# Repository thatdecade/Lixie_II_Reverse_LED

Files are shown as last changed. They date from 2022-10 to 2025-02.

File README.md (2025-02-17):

# Remix of Lixie II Open Hardware
Want to make your own Lixie II, but don't want to spend $$$$? You're in the right place. 

Based on the original work by Connor Nishijima: https://github.com/connornishijima/Lixie_II_OSHW

**Photo Album**
https://photos.app.goo.gl/PVswYqP2KvHP66T27

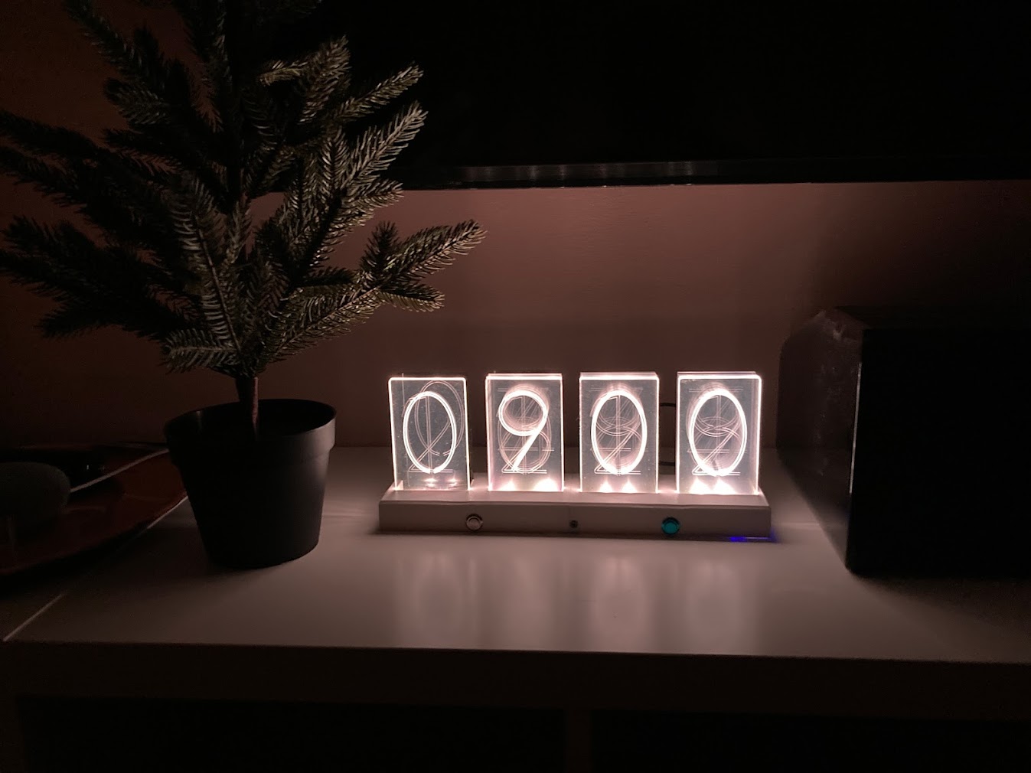
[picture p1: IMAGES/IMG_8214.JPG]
Assembled Lixie Clock with Reverse LEDs


## Remix Notes
- PCB redrawn with a new BOM, using reverse mount LEDs. https://www.adafruit.com/product/4960
  - Loosely based on Adafruit's RGB NeoKey https://www.adafruit.com/product/5157
  - One capacitor per LED
  - Transmission resistors for stable data
- EPS files for lasercutting were converted to DXF.
- Laser Cut files have been redrawn for smaller runs.  
  - Ordering one set = One Digit of the Display
  - Ponoko wil auto-panelize larger orders together.
  - Be sure to read https://help.ponoko.com/en/articles/4405518-getting-started-with-ponoko
- 3D Printed versions of some of the lasercut files

|Filename|Supplier|Material|Thickness|
| --- | --- | --- | --- |
|BASEx2.dxf|Ponoko|Black Melamine MDF|6.4|
|NUM0-9.dxf|Ponoko|Clear Acrylic|1.5|
|DECIMAL.dxf|Ponoko|Gray Translucent Acrylic|3|
|LIGHTFILTER.dxf|Ponoko|6061-T6 Aluminum|1|

- LixieII_Price_Calculator.xlsx calculates the cost (including electronics) based on how many you would like to make.  
Here are some BOM estimates as of Oct 28, 2022:

|QTY|Total Cost|Cost Each|
| --- | --- | --- |
|1|$166|$166|
|2|$233|$117|
|4|$255|$64|
|8|$392|$49|
|10|$446|$45|
|16|$665|$42|
|32|$1250|$39|
|200|$4740|$24|

## Todo

- Convert Lightplate into pcb gerbers for cheaper cutting

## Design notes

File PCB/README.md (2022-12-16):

Here you will find the files for the PCB.  

To order the PCBs pre-assembled, visit [pcbshopper](https://pcbshopper.com/) and click the Assembly tab.  Then you can fill out the form and compare pricing from different assemblers.

## Files for assembly:

* Lixie_II_Reverse_LED_GERBERS.zip
* Lixie_II_Reverse_LED_BOM.xlsx
* Lixie_II_Reverse_LED_PLACEMENT.xlsx

## Notes:

* If you don't have EagleCAD to open the .brd/.sch files, you can use the free version of Autodesk Fusion 360 and download Eagle Free.
* I use eagle to generate the .dxf files, ensuring alignment between the pcb and other layers.  

## Generating the DXF Files
Example for LIGHTFILTER.dxf
1. Open the the .brd file in eagle
1. View>Layer Settings: 
> * Select None
> * Select only the LIGHTFILTER/ENGRAVING layers
3. File>Export>DXF: 
> * Name the output file: LIGHTFILTER.dxf
> * Unselect Fill areas
> * Unselect Use wire widths
> * Set Units to mm
> * Press OK



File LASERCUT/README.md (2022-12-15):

These are the files to uplaod to Ponoko for laser cutting.  
Example below, how to fill out the order form and assign colors to each laser process.

Note: If you have a 3D printer, you can skip the BASE lasercut parts and use the 3d printed version instead.

ponoko_example_upload

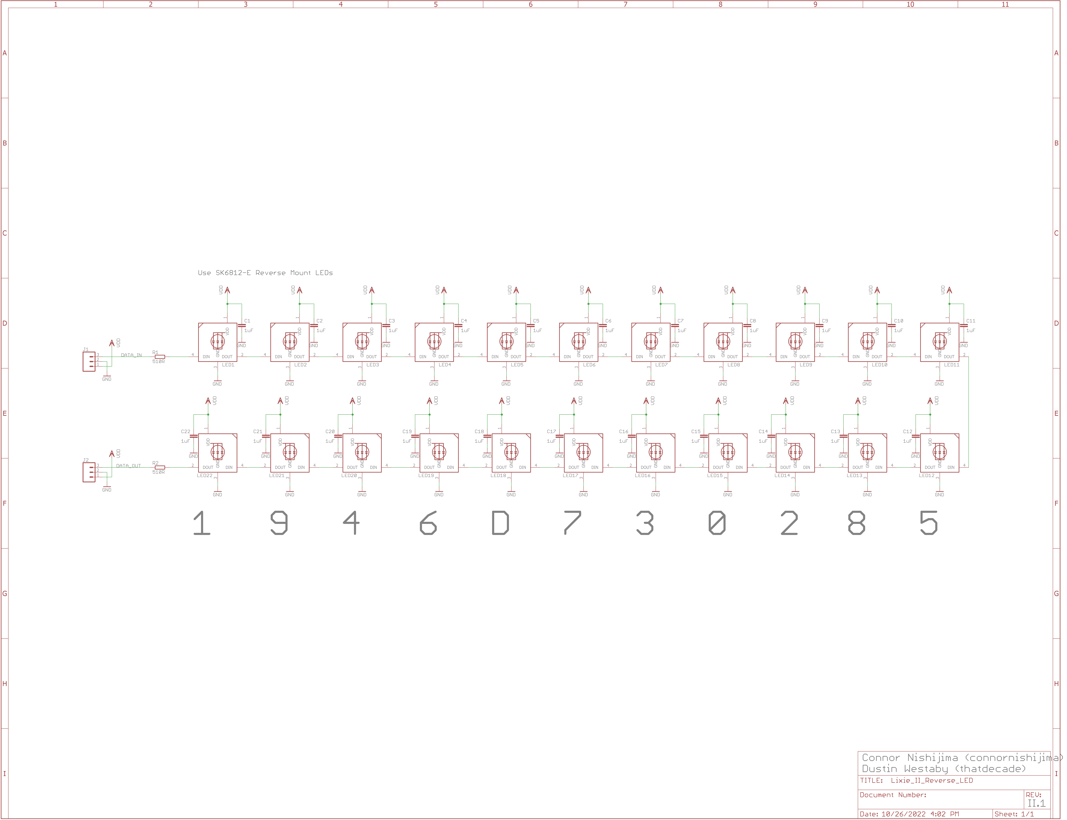
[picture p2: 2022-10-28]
PCB/Lixie_II_Reverse_LED_Schematic.png

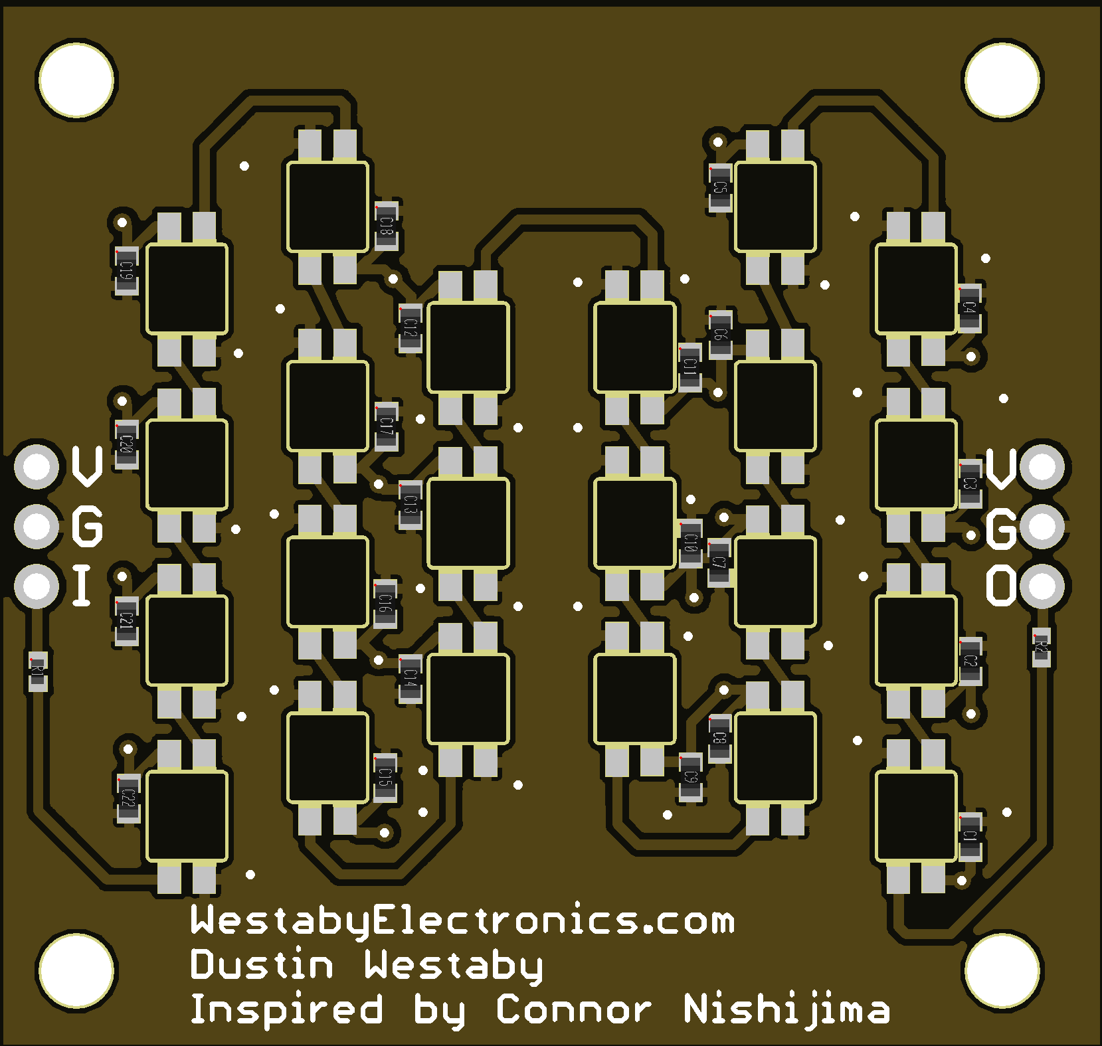
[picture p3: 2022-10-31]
PCB/Lixie_II_Reverse_LED_2D_Render.png

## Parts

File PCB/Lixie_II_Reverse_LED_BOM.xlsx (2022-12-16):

Comment | Designator | Footprint | JLCPCB Part # | Value
Capacitor | C1 | C0603 | C15849 | 1uF
Capacitor | C2 | C0603 | C15849 | 1uF
Capacitor | C3 | C0603 | C15849 | 1uF
Capacitor | C4 | C0603 | C15849 | 1uF
Capacitor | C5 | C0603 | C15849 | 1uF
Capacitor | C6 | C0603 | C15849 | 1uF
Capacitor | C7 | C0603 | C15849 | 1uF
Capacitor | C8 | C0603 | C15849 | 1uF
Capacitor | C9 | C0603 | C15849 | 1uF
Capacitor | C10 | C0603 | C15849 | 1uF
Capacitor | C11 | C0603 | C15849 | 1uF
Capacitor | C12 | C0603 | C15849 | 1uF
Capacitor | C13 | C0603 | C15849 | 1uF
Capacitor | C14 | C0603 | C15849 | 1uF
Capacitor | C15 | C0603 | C15849 | 1uF
Capacitor | C16 | C0603 | C15849 | 1uF
Capacitor | C17 | C0603 | C15849 | 1uF
Capacitor | C18 | C0603 | C15849 | 1uF
Capacitor | C19 | C0603 | C15849 | 1uF
Capacitor | C20 | C0603 | C15849 | 1uF
Capacitor | C21 | C0603 | C15849 | 1uF
Capacitor | C22 | C0603 | C15849 | 1uF
Resistor | R1 | R0402 | C25123 | 510R
Resistor | R2 | R0402 | C25123 | 510R
Connector | J1 | 1X03_NO_SILK |  | 1x3
Connector | J2 | 1X03_NO_SILK |  | 1x3
Reverse Mount LED | LED1 | SK6812-E-SMD |  | SK6812MINI_REV
Reverse Mount LED | LED2 | SK6812-E-SMD |  | SK6812MINI_REV
Reverse Mount LED | LED3 | SK6812-E-SMD |  | SK6812MINI_REV
Reverse Mount LED | LED4 | SK6812-E-SMD |  | SK6812MINI_REV
Reverse Mount LED | LED5 | SK6812-E-SMD |  | SK6812MINI_REV
Reverse Mount LED | LED6 | SK6812-E-SMD |  | SK6812MINI_REV
Reverse Mount LED | LED7 | SK6812-E-SMD |  | SK6812MINI_REV
Reverse Mount LED | LED8 | SK6812-E-SMD |  | SK6812MINI_REV
Reverse Mount LED | LED9 | SK6812-E-SMD |  | SK6812MINI_REV
Reverse Mount LED | LED10 | SK6812-E-SMD |  | SK6812MINI_REV
Reverse Mount LED | LED11 | SK6812-E-SMD |  | SK6812MINI_REV
Reverse Mount LED | LED12 | SK6812-E-SMD |  | SK6812MINI_REV
Reverse Mount LED | LED13 | SK6812-E-SMD |  | SK6812MINI_REV
Reverse Mount LED | LED14 | SK6812-E-SMD |  | SK6812MINI_REV
Reverse Mount LED | LED15 | SK6812-E-SMD |  | SK6812MINI_REV
Reverse Mount LED | LED16 | SK6812-E-SMD |  | SK6812MINI_REV
Reverse Mount LED | LED17 | SK6812-E-SMD |  | SK6812MINI_REV
Reverse Mount LED | LED18 | SK6812-E-SMD |  | SK6812MINI_REV
Reverse Mount LED | LED19 | SK6812-E-SMD |  | SK6812MINI_REV
Reverse Mount LED | LED20 | SK6812-E-SMD |  | SK6812MINI_REV
Reverse Mount LED | LED21 | SK6812-E-SMD |  | SK6812MINI_REV
Reverse Mount LED | LED22 | SK6812-E-SMD |  | SK6812MINI_REV

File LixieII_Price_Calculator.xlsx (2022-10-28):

 |  |  |  |  | Qty
 |  |  |  | ENTER QUANTITY YOU WOULD LIKE TO MAKE HERE ----> | 10
 |  |  |  | Estimated Cost-----> | $445.85
 |  |  |  |  |  |  |  |  |  |  |  |  | Prices quoted on 10/27/2022 from ponoko.com
Description | Supplier | Material | Thickness |  | Qty | Price | Handling | Shipping | Each | Qty per Display Digit | Cost Per Display Digit | Notes | Price Lookups | BASES | NUMS0-9 | DECIMAL | Light Filter | Price Lookups | PCB | Price Lookups | LEDs | Price Lookups | Gloves | Price Lookups | Screw 35mm | Screw 25mm | Price Lookups | Nylon Washer | Price Lookups | Nut | Price Lookups | Female Wire
BASEx2.dxf | Ponoko | Black Melamine MDF | 6.4 |  | 10 | $77.40 |  |  | $7.74 | 1 | $7.74 |  | 1 | 16.62 | 31.01 | 10.76 | 8.84 | 5 | 11.5 | 50 | 6.46 | 100 | 12.75 | 200 | 8.16 | 6.56 | 100 | 2.17 | 50 | 3.81 | 40 | 2.24
NUM0-9.dxf | Ponoko | Clear Acrylic | 1.5 |  | 10 | $171.70 |  |  | $17.17 | 1 | $17.17 |  | 4 | 9.1 | 19.22 | 5.62 | 4.25 | 10 | 14.5 | 100 | 10.2 | 200 | 25.5 | 400 | 16.32 | 13.12 | 200 | 3.4 | 100 | 8.02 | 80 | 3.11
DECIMAL.dxf | Ponoko | Gray Translucent Acrylic | 3.0 |  | 10 | $34.90 |  |  | $3.49 | 1 | $3.49 |  | 5 | 8.89 | 18.11 | 5.33 | 3.96 | 15 | 16 | 200 | 16.57 | 300 | 38.25 | 600 | 24.48 | 19.68 | 300 | 4.63 | 150 | 10.99 | 120 | 3.98
LIGHTFILTER.dxf | Ponoko | 6061-T6 Aluminum | 1.0 |  | 10 | $33.40 |  |  | $3.34 | 1 | $3.34 | Replace with PCB? | 8 | 8.02 | 17.54 | 4.84 | 3.48 | 20 | 16.8 | 300 | 24.05 | 400 | 51 | 800 | 32.64 | 26.24 | 400 | 7.28 | 200 | 13.97 | 160 | 4.85
 |  |  |  |  |  |  |  |  |  |  |  |  | 10 | 7.74 | 17.17 | 3.49 | 3.34 | 25 | 17.6 | 500 | 36.12 | 500 | 63.75 | 1000 | 40.8 | 32.8 | 500 | 8.59 | 250 | 16.95 | 200 | 6.86
Description | Supplier | Link |  |  | Qty | Price |  | Shipping | Each | Qty per Display Digit | Cost Per Display Digit | Notes | 50 | 4.91 | 12.02 | 2.7 | 1.91 | 30 | 18.4 | 1000 | 65.87 | 600 | 76.5 | 1200 | 48.96 | 39.36 | 600 | 9.89 | 300 | 19.92 | 240 | 7.73
PCB | JLC | PCB |  |  | 10 | $24.50 |  | $40.00 | $6.45 | 1 | $6.45 |  | 100 | 4.43 | 10.59 | 2.03 | 1.37 | 50 | 22.9 | 2000 | 121.97 | 700 | 89.25 | 1400 | 57.12 | 45.92 | 700 | 11.19 | 350 | 22.9 | 280 | 8.6
Reverse Mount LEDs | veromount Official Store | https://www.aliexpress.us/item/3256804063632410.html?mp=1&_randl_shipto=US |  |  | 300 | $24.05 |  |  | $0.08 | 22 | $1.76 |  | 500 | 3.21 | 8.36 | 1.57 | 1.12 | 75 | 59.16 | 4000 | 243.94 |  |  |  |  |  | 1000 | 15.11 | 500 | 31.83 | 320 | 9.47
Nitrile Gloves | Sinier Store Store | https://www.aliexpress.us/item/3256803590949003.html?curPageLogUid=DwKQPqTq5PrM |  |  | 100 | $12.75 |  |  | $0.13 | 2 | $0.26 |  | 1000 | 2.84 | 7.22 | 1.4 | 0.99 | 100 | 64.76 | 6000 | 365.91 |  |  |  |  |  | 1500 | 21.63 | 1000 | 61.59 | 360 | 10.34
35mm M3 Screw | SHOUZHENG FASTENER Store | https://www.aliexpress.com/item/3256804033774565.html?spm=a2g0o.cart.0.0.26bd38daxLe5zc&mp=1 |  |  | 200 | $8.16 |  |  | $0.04 | 4 | $0.16 |  | 5000 | 1.89 | 4.42 | 1.05 | 0.71 | 125 | 70.36 | 8000 | 487.88 |  |  |  |  |  | 2000 | 28.15 | 1500 | 91.35 | 400 | 11.21
25mm M3 screw | SHOUZHENG FASTENER Store | https://www.aliexpress.com/item/3256804033774565.html?spm=a2g0o.cart.0.0.26bd38daxLe5zc&mp=1 |  |  | 200 | $6.56 |  |  | $0.03 | 4 | $0.13 |  | 10000 | 1.5 | 3.73 | 0.87 | 0.6 | 150 | 76.06 |  |  |  |  |  |  |  | 2500 | 34.67 | 3000 | 180.63 | 440 | 12.08
Nylon washer | SHOUZHENG FASTENER Store | https://www.aliexpress.com/item/3256803969060157.html?spm=a2g0o.cart.0.0.1a8138davO6E52&mp=1 |  |  | 100 | $2.17 |  |  | $0.02 | 8 | $0.17 |  |  |  |  |  |  | 200 | 87.26 |  |  |  |  |  |  |  |  |  |  |  | 480 | 12.95
M3 Flange Nut | SHOUZHENG FASTENER Store | https://www.aliexpress.com/item/3256804055381890.html?spm=a2g0o.cart.0.0.4f8138daJxUMmj&mp=1 |  |  | 100 | $8.02 |  |  | $0.08 | 8 | $0.64 |  |  |  |  |  |  | 250 | 98.56 |  |  |  |  |  |  |  |  |  |  |  | 520 | 13.82
Female Jumper Wires 10cm | Fnd Chips Store | https://www.aliexpress.us/item/3256804425682359.html?curPageLogUid=pjq9i1GZgUdJ |  |  | 40 | $2.24 |  |  | $0.06 | 3 | $0.17 |  |  |  |  |  |  |  |  |  |  |  |  |  |  |  |  |  |  |  | 560 | 14.69
ESP8266 |  |  |  |  |  |  |  |  |  |  |  |  |  |  |  |  |  |  |  |  |  |  |  |  |  |  |  |  |  |  | 600 | 15.56
 |  |  |  |  |  |  |  |  |  |  |  |  |  |  |  |  |  |  |  |  |  |  |  |  |  |  |  |  |  |  | 640 | 16.43
 | Estimations (Pre-Calculated)
 | QTY | Total Cost | Cost Each
 | 1 | $165.88 | $165.88
 | 2 | $233.11 | $116.555
 | 4 | $255.15 | $63.7875
 | 8 | $392.01 | $49.00125
 | 10 | $445.85 | $44.585
 | 16 | $665.73 | $41.608125
 | 32 | $1250.45 | $39.0765625
 | 200 | $4739.73 | $23.69865

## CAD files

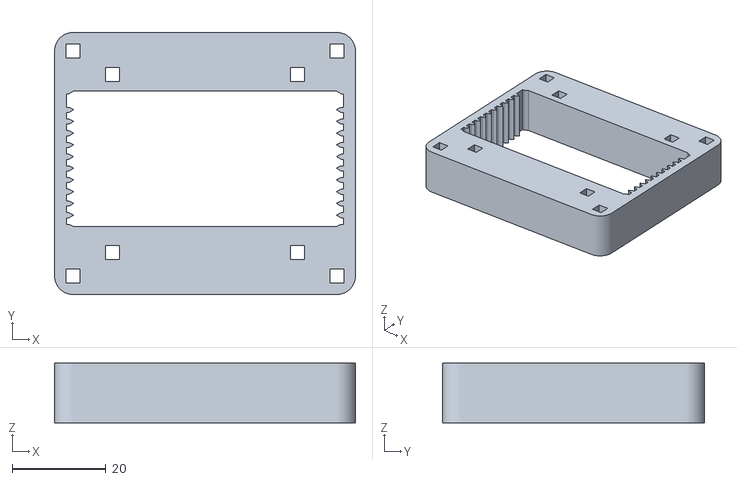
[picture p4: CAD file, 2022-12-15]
3D Printing/BASE.stl
64.3 x 56.0 x 12.8

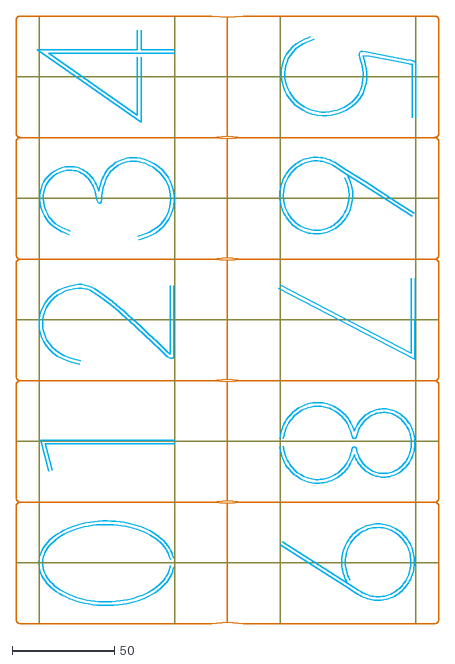
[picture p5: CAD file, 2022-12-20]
LASERCUT/NUM0-9.dxf
206.2 x 296.7

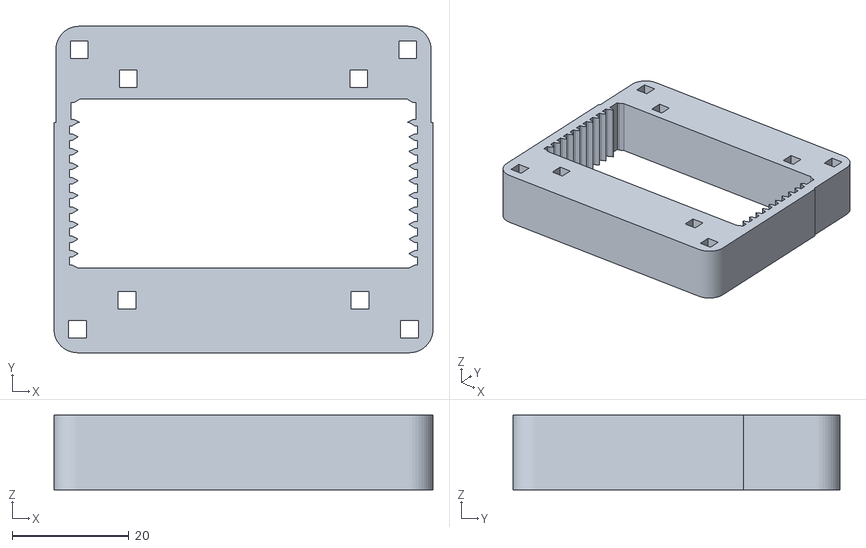
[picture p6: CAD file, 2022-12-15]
3D Printing/BASE-Loose_Fit.stl
64.9 x 56.0 x 12.8

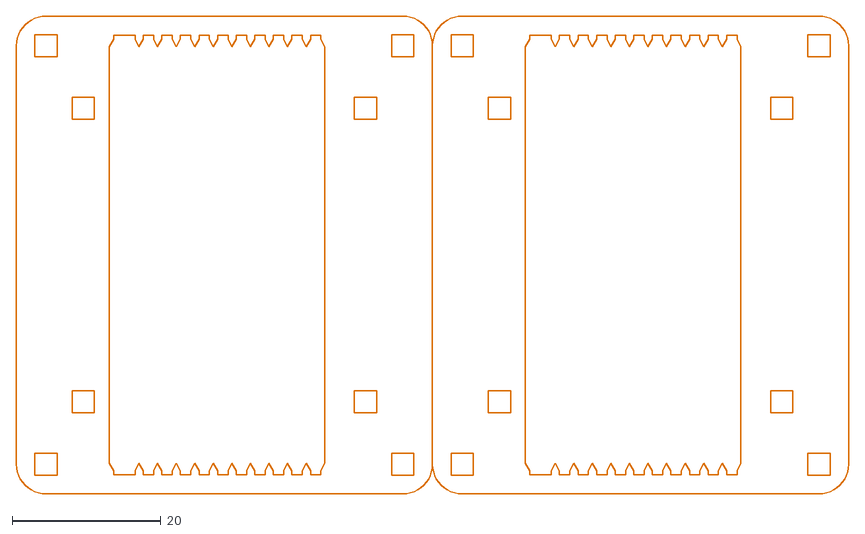
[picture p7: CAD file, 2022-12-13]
LASERCUT/BASEx2.dxf
112.0 x 64.3

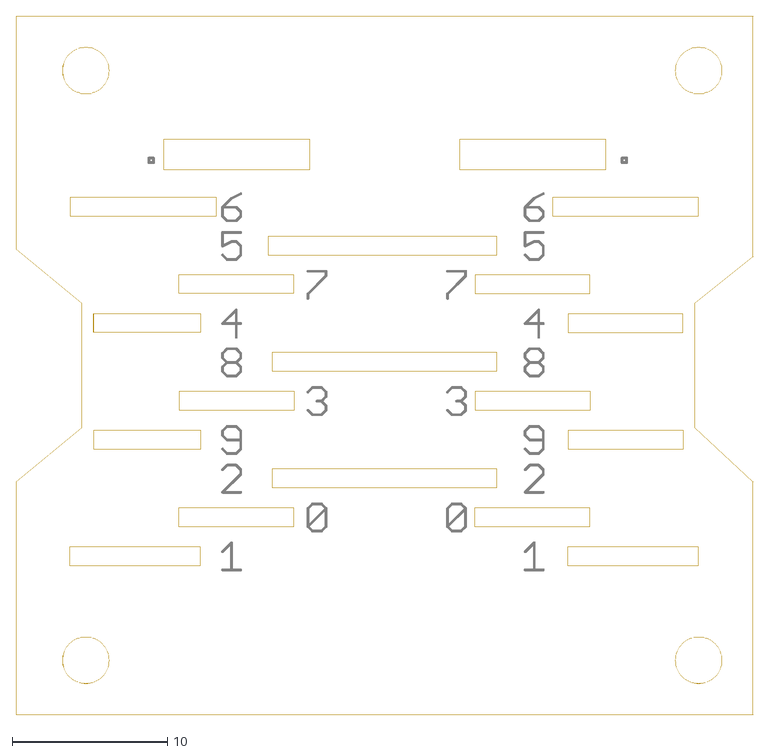
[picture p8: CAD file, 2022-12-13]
LASERCUT/LIGHTFILTER.dxf
47.5 x 45.0

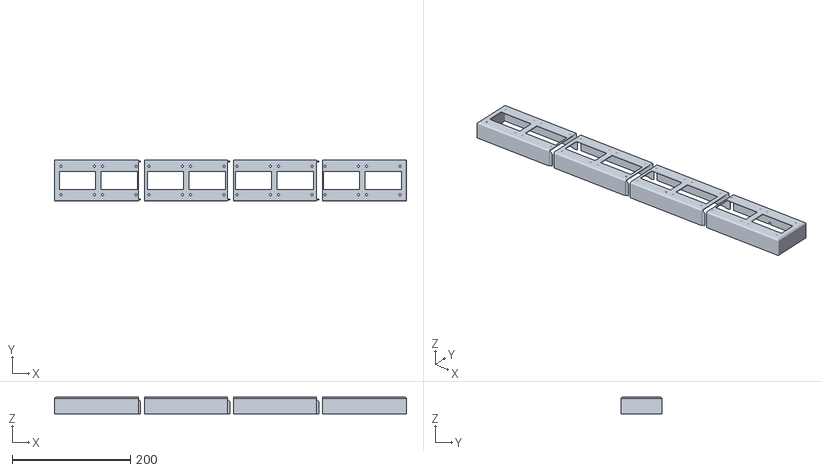
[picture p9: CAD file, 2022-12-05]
3D Printing/Lixie_II_Case_8_digits.stl
594.4 x 70.0 x 28.0

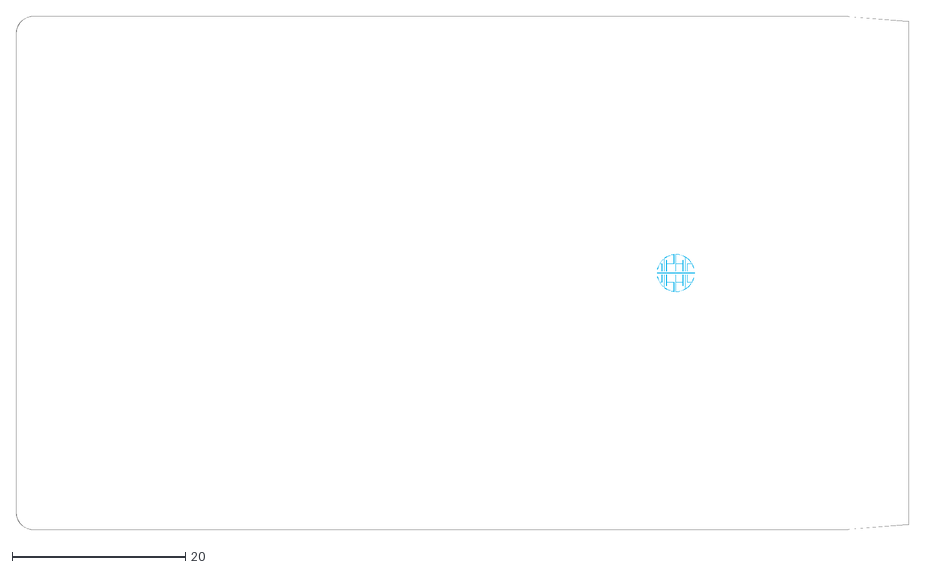
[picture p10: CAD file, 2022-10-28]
LASERCUT/DECIMAL.dxf
103.1 x 59.3

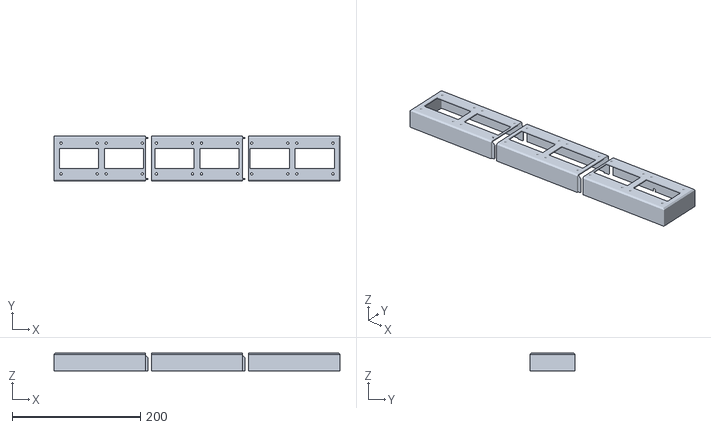
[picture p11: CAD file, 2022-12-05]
3D Printing/Lixie_II_Case_6_digits.stl
445.8 x 70.0 x 28.0

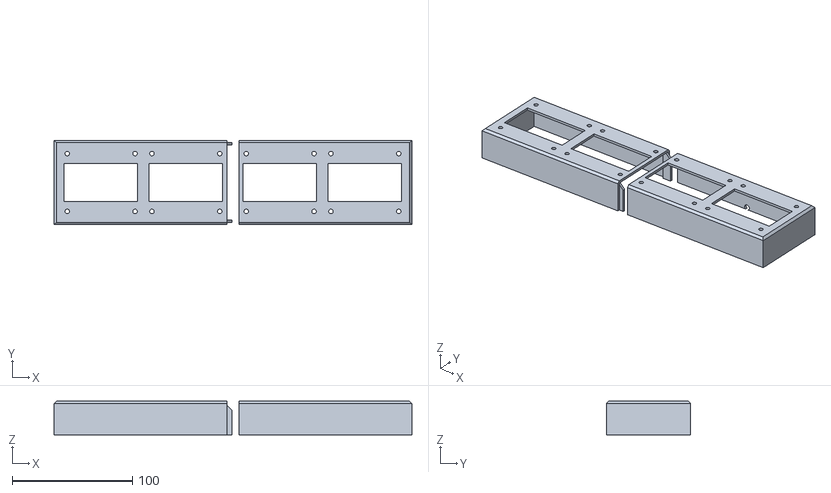
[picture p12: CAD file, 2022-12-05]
3D Printing/Lixie_II_Case_4_digits.stl
297.2 x 70.0 x 28.0

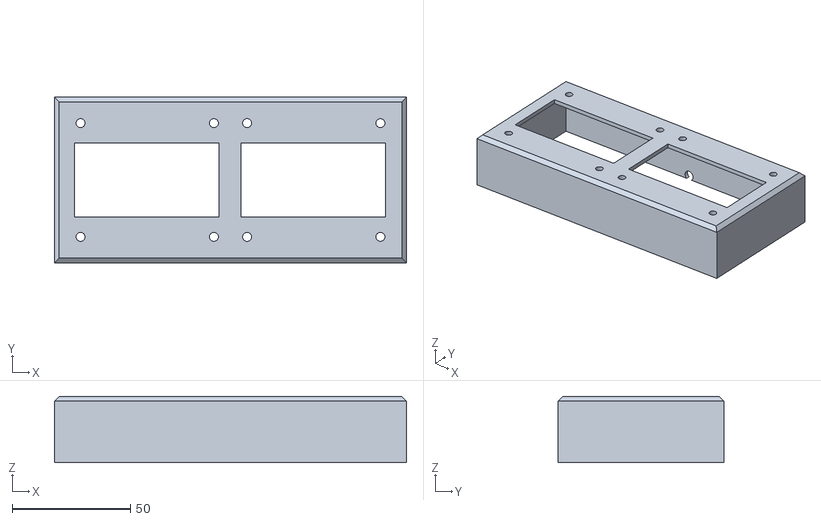
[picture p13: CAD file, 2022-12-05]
3D Printing/Lixie_II_Case_2_digits.stl
148.6 x 70.0 x 28.0

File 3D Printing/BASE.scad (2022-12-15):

/* This is a customizable housing for lixie displays

    Dustin Westaby 
    Nov 2022

    USAGE:
    
    Enter the number of displays you want, and you will get an object that you can print as is, or split up for your printer
    
*/

// ********************
// USER DEFINES
// ********************
// Set options here

black_melamine_mdf_thickness = 6.4;
mdf_stack_height = 2;

want_tolerance_for_acrylic  = 1;
want_screw_threaded_inserts = 1;

// ********************
// CALCULATED
// ********************

loose_fit = 2.0;
slide_fit = 0.2;
friction_fit = 0.02;

total_height = black_melamine_mdf_thickness*mdf_stack_height;

// ********************
// MODULES
// ********************

difference()
{
    union()
    {
        base_slice("3mm holder");
        base_slice("1.5mm holder");
    }
    if(want_screw_threaded_inserts) threaded_inserts();
}

module base_slice(part="3mm holder")
{
    scale_adj      = (part=="3mm holder") ? 1 : 1.01;
    x_position_adj = (part=="3mm holder") ? 0 : -0.25;
    
    translate([x_position_adj,0,0])
    linear_extrude(height=total_height)
    {
        scale([scale_adj,1,1]) //no scale change
        difference()
        {
            if(want_screw_threaded_inserts) import("BASE_NoHoles.dxf");
            else                            import("BASE.dxf");
            
            if(want_tolerance_for_acrylic)
            {
                if(part=="3mm holder") translate([-8,-8,0]) square(size = [65, 42]);
                else translate([-8,42-8,0]) square(size = [65, 20]);
            }

        }
    }
}

module threaded_inserts()
{
    
    insert_hole_diameter = 3.73 + slide_fit;
    $fn=25;
    
    //inner holes
    translate([ 4.7,41.54,-1]) cylinder(d=insert_hole_diameter, h= total_height+2);
    translate([44.2,41.54,-1]) cylinder(d=insert_hole_diameter, h= total_height+2);
    translate([ 4.7,3.54,-1]) cylinder(d=insert_hole_diameter, h= total_height+2);
    translate([44.2,3.54,-1]) cylinder(d=insert_hole_diameter, h= total_height+2);
    
    //outer holes
    translate([ -3.7,46.55,-1]) cylinder(d=insert_hole_diameter, h= total_height+2);
    translate([52.6,46.55,-1]) cylinder(d=insert_hole_diameter, h= total_height+2);
    translate([ -3.7,-1.45,-1]) cylinder(d=insert_hole_diameter, h= total_height+2);
    translate([52.6,-1.45,-1]) cylinder(d=insert_hole_diameter, h= total_height+2);
}

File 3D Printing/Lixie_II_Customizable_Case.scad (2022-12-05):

/* This is a customizable housing for lixie displays

    Dustin Westaby 
    Nov 2022

    USAGE:
    
    Enter the number of displays you want, and you will get an object that you can print as is, or split up for your printer
    
*/

// ********************
// USER DEFINES
// ********************
// Set options here

digits = 2; //Min is 1

chamfer = 2;

screw_hole_diameter = 3; //M3 = 3mm

want_button = 0;

want_power_cable = 1;

want_pre_cuts_and_glue_tabs = 1;

switch_hole_diameter = 12; //set want_button=1

usb_cable_diameter = 5;  //set want_power_cable=1

window_x = 59.05;
window_y = 29.20;

max_printer_bed_size = 180; //set want_pre_cuts_and_glue_tabs=1, Prusa Mk3 = 21cm (8.3")

// ********************
// CALCULATED
// ********************

side_wall_thickness = 2; //2 or 3mm

top_wall_thickness = 2 ;

loose_fit = 2.0;
slide_fit = 0.2;
friction_fit = 0.02;

center_digits = digits-2;

edge_length = 74.3;
center_length = 70.3;

outer_length_x = edge_length*2 + center_digits*center_length;
outer_width_y  = 70;

outer_depth_z  = 26 + top_wall_thickness;

switch_hole_z_offset_from_center = outer_depth_z/2-top_wall_thickness/2;

window_x_size_adj = window_x + loose_fit;
window_y_size_adj = window_y + loose_fit;

glue_tab_insert_depth = 4;

// ********************
// MODULES
// ********************

//max_printer_bed_size
if((want_pre_cuts_and_glue_tabs == 0) || outer_length_x < max_printer_bed_size)
{
    draw_body();
}
else
{
    cut_offsets = glue_tab_insert_depth*2;
    
    //cut up the body every max_printer_bed_size size

    number_of_cuts = ceil(outer_length_x / max_printer_bed_size); //round up
    negative_width = number_of_cuts - 1;
    
    //left side
    draw_body_cut(
        x1_position = outer_length_x * 1 / number_of_cuts, 
        cut_width  = outer_length_x  * negative_width / number_of_cuts, 
        cut_offset = cut_offsets * 0, 
        want_tabs  = true);
    
    //inner parts
    if(number_of_cuts-2 > 0)
    {
        for(i = [1 : number_of_cuts-2])
        {
            cut_width = outer_length_x  * negative_width / number_of_cuts;
            slice_width = outer_length_x / number_of_cuts;
            
            draw_body_cut(
                x1_position = -cut_width+slice_width*i, 
                x2_position = slice_width*(i+1), 
                cut_width  = cut_width,
                cut_offset = cut_offsets * i, 
                want_tabs  = true);
        }
    }
    
    //right side
    draw_body_cut(
        x1_position = 0, 
        cut_width  = outer_length_x  * negative_width / number_of_cuts, 
        cut_offset = cut_offsets * (number_of_cuts-1), 
        want_tabs  = false);
    
}

module draw_body_cut(x1_position, x2_position=0, cut_width, cut_offset, want_tabs=false)
{
    translate([cut_offset,0,0]) 
    difference()
    {
        draw_body();
        
        //cutter 1
        translate([x1_position-1,-1,-1]) 
        cube([cut_width+2,outer_width_y+2,outer_depth_z+2]);
        
        //cutter 2
        if(x2_position != 0) translate([x2_position-1,-1,-1]) 
        cube([cut_width+2,outer_width_y+2,outer_depth_z+2]);
    }
    if(want_tabs)
    {
        if(x2_position > 0)
        {
            glue_tabs((x2_position - 1 + cut_offset) - glue_tab_insert_depth);
        }
        else
        {
            glue_tabs((x1_position - 1) - glue_tab_insert_depth);
        }
    }
}

module draw_body()
{
    difference()
    {
        union()
        {
            outer_base_shape(use_chamfer=true);
            if(want_button) draw_switch_outline();
        }
        
        inner_base_shape();
        
        display_and_screw_cutouts();
        
        if(want_button) draw_button();
            
        if(want_power_cable) draw_power_cable();
    }
}

//TBD, tabs
module glue_tabs(x_position)
{
    translate([x_position,0,0])
    {
        translate([0,side_wall_thickness,0])
        glue_tab();
        
        translate([0,outer_width_y-side_wall_thickness*2,0])
        glue_tab();
    }
}

module glue_tab()
{
    z_alignment = 0.5;
    
    tab_height = outer_depth_z-top_wall_thickness*2-4;
    
    //tab
    cube([glue_tab_insert_depth*2, side_wall_thickness, tab_height+z_alignment]);
    
    //printability ledge
    translate([-glue_tab_insert_depth+0.68,0,0])
    difference()
    {
        translate([0,0,tab_height+z_alignment])
        rotate([0,45,0]) cube([glue_tab_insert_depth*2, side_wall_thickness, glue_tab_insert_depth*2]);
        
        translate([-glue_tab_insert_depth*1.17,-2,0])
        cube([glue_tab_insert_depth*2, side_wall_thickness+4, tab_height*2+z_alignment]);
    }
}


module draw_power_cable()
{
    
    hole_depth = side_wall_thickness*2;
    x_position = outer_length_x-(edge_length-side_wall_thickness*2);
    
    //switch_hole_diameter
    translate([x_position,outer_width_y-hole_depth-0.1,usb_cable_diameter/2-0.5]) 
    //cube([usb_cable_diameter,hole_depth+0.2,usb_cable_diameter]);
    rotate([-90,0,0])
    cylinder(d=usb_cable_diameter, h=hole_depth+0.2, $fn=25);
}

module screw_hole()
{
    //for nuts and bolts to BASES.dxf
    cylinder(d=screw_hole_diameter + slide_fit*2 + slide_fit*2, h=outer_depth_z*2, $fn=25);
}

module screw_hole_set(x_offset)
{
    edge_x_offset = 11+x_offset;
    edge_y_offset = 11;
    window_width = 56.3;
    
    translate([edge_x_offset,edge_y_offset,0]) screw_hole();
    translate([edge_x_offset,outer_width_y-edge_y_offset,0]) screw_hole();
    
    translate([window_width+edge_x_offset,edge_y_offset,0]) screw_hole();
    translate([window_width+edge_x_offset,outer_width_y-edge_y_offset,0]) screw_hole();
}

module draw_button()
{
    draw_switch_holes();
}


module draw_switch_cyl(diameter)
{
    hole_depth = side_wall_thickness*1.1;
    x_position = outer_length_x-(edge_length-side_wall_thickness*2);
    
    //switch_hole_diameter
    translate([x_position,0+hole_depth/2-0.01,switch_hole_z_offset_from_center]) rotate([90,0,0]) cylinder(h=hole_depth, d=diameter);
}

module draw_switch_outline()
{
    switch_outline_pad = 2.25;
    draw_switch_cyl(switch_hole_diameter+switch_outline_pad);
}

module draw_switch_holes()
{
    translate([0,-0.01,0]) draw_switch_cyl(switch_hole_diameter);
    translate([0,2,0]) draw_switch_cyl(switch_hole_diameter+4);
}


module display_and_screw_cutouts()
{
    x_offset = center_length;
    
    display_cutout(0);
    screw_hole_set(0);
    
    if(center_digits > 0)
    {
        for(i = [0 : center_digits])
        {
            screw_hole_set(x_offset*(i+1));
            display_cutout(x_offset*(i+1));
        }
        display_cutout(x_offset*(center_digits+1));
    }
    else
    {
        display_cutout(x_offset);
        screw_hole_set(x_offset);
    }
}

module display_cutout(x_offset)
{
    display_x_position = -window_x_size_adj/2+39+x_offset;
    display_y_position = -window_y_size_adj/2+35;
    
    translate([display_x_position,display_y_position,-0.5])
    cube([window_x_size_adj,window_y_size_adj,outer_depth_z+1]);
}

module outer_base_yz_2d_shape(chamfer_adj)
{
    polygon(points=[
        [0,0],
        [outer_depth_z-chamfer_adj, 0],
        [outer_depth_z,             chamfer_adj],
        [outer_depth_z,             outer_width_y-chamfer_adj],
        [outer_depth_z-chamfer_adj, outer_width_y],
        [0,                         outer_width_y],
    ]);
}

module outer_base_xz_2d_shape(chamfer_adj)
{
    polygon(points=[
        [0,0],
        [outer_depth_z-chamfer_adj, 0],
        [outer_depth_z,             chamfer_adj],
        [outer_depth_z,             outer_length_x-chamfer_adj],
        [outer_depth_z-chamfer_adj, outer_length_x],
        [0,                         outer_length_x],
    ]);
}


module outer_base_shape(use_chamfer)
{
    chamfer_adj = use_chamfer ? chamfer : 0;
    
    intersection()
    {
        translate([outer_length_x,0,0])
        rotate([0,-90,0])
        linear_extrude(outer_length_x) 
        outer_base_yz_2d_shape(chamfer_adj);
        
        translate([0,0,0])
        rotate([-90,-90,0])
        linear_extrude(outer_width_y) 
        outer_base_xz_2d_shape(chamfer_adj);
    }
}

module inner_base_shape()
{
    translate([side_wall_thickness,side_wall_thickness,-0.1])
    resize([outer_length_x-side_wall_thickness*2, outer_width_y-side_wall_thickness*2, outer_depth_z-top_wall_thickness]) 
    outer_base_shape(use_chamfer=false);
}   

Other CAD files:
3D Printing/BASE_Threaded_Inserts.stl

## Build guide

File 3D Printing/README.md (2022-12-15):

# 3D Printed Case

With access to a 3d printer, you can skip lasercutting the BASE parts.  Use the 3d printable BASE.stl here.  Uses M3 Heat Sets instead of nuts.
https://amzn.to/3jbxNs8 

You can use one of the default .stl files, or use the .scad file and OpenSCAD to make your own configuration.  

Recommend cutting the object smaller to fit your print bed, or adding glue tabs to help with assembly.

--------------
We are a participant in the Amazon Services LLC Associates Program, an affiliate advertising program designed to provide a means for us to earn fees by linking to Amazon.com and affiliated sites.

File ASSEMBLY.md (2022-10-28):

To put this kit together, you will need to order parts below.  One set per digit of your display.

**Not listed**: Arduino-compatible dev board to drive the lights.  Wifi enabled ESP8266 is recommended.

* Laser cut parts
  * BASEx2.dxf
  * NUM0-9.dxf
  * DECIMAL.dxf
  * LIGHTFILTER.dxf

* PCB Assemblies
  * Lixie_II_Reverse_LED_GERBERS.zip
  * Lixie_II_Reverse_LED_BOM.xlsx
  * Lixie_II_Reverse_LED_PLACEMENT.xlsx

* Hardware store
  * 2x Nitrile Gloves
  * 4x 35mm M3 Screw
  * 4x 25mm M3 screw
  * 8x Nylon washer
  * 8x M3 Flange Nut
  * 3x Female Jumper Wires 10cm

# Lixie Base Assembly

* Stack the two black melamine wood base pieces.  Orient so that the thicker 3mm slot is farthest from you.
* Insert 4x 25 mm screw and 4x washers through each of the four inner holes.
* Insert 4x 35 mm screw and 4x washers through each of the four outer holes.
* Add the light filter to the stack. 
* Add the PCB to the stack.
* Take a moment to examine your stack.  
  * Each layer should sit completly flush, with no gaps.  
  * The LEDs should face through the light filter.
  * The LEDs and Light filter should line up with each acrylic slot.
  * Don't worry if you got the orientations wrong, you can always take it apart and try again :)
* Now is time to add the nuts.  Gently tighten 8x flange nuts to the screws.

# Acrylic Assembly

* Peel the paper backing from each acrylic digit and place straight into the Lixie Base.
* There is no step 2.

**Notes:**
- The order of each acrylic digit is important (front to back): 1 0 2 9 3 8 4 7 5 6 .
- Before working with the acrylic, it is important that you wear gloves.  Fingerprints can be cleaned from the acrylic, but let's try and skip that step.
- Peeling from the bottom of each digit will allow you to hide any initial blemishes.
- At the end, you may see bits of dust or paper shreds stuck to the acrylic.  Blast with a little compressed air.

# Power Up and Programming

There are three pins on each side of the PCB.  Allowing you to daisy chain many displays.
If you plan for more than 10 displays, you may want to look into running additional wires from the one power supply to both sides of the chain.

For the data wires, the LEDs are 5V.  So if your arduino-compatible board is 3.3V like the ESP8266 then you either need to keep the data wire lengths short (under 10cm) or you need a 3.3V to 5V converter circuit. More info: https://learn.adafruit.com/neopixel-levelshifter

You can see programming examples from the main Lixie repo: https://github.com/connornishijima/Lixie_II

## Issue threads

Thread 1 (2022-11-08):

Pins short out to the light plate

thatdecade, 2022-11-08:
The light filter is made of aluminum and touches the V / Data / Pins.  Short term fix is cutting the pins flush and covering with tape.

A more permanent solution would be updating the light filter to include cutouts for the comm pins.

Closed 2022-12-13.

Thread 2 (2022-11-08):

Light filter has leaks between digits

thatdecade, 2022-11-08:
The slots on the light filter are too wide, allowing neighboring LEDs to shine through adjacent slots.

Closed 2022-12-13.

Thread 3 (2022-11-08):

pin1 indicator is on the wrong silkscreen

thatdecade, 2022-11-08:
When assembling the LEDs to the PCB, there is no pin1 indicator on the same side as the LED is installed.  Add pin1 indicators to both sides of the pcb silkscreen.

Closed 2022-12-13.

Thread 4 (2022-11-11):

3d printed case, opening too small for display

thatdecade, 2022-11-11:
The plexiglass plates do not fit below the case.  Mounting on top fits ok, but would be cleaner to mount the BASE parts inside the case.

thatdecade, 2022-12-05:
Fixed

Closed 2022-12-05.

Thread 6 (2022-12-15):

Lightfilter is relatively expensive

thatdecade, 2022-12-15:
The lasercut aluminum works well as a light filter, giving nice hard edges.  Can this be duplicated with a PCB or 3d printed shape?

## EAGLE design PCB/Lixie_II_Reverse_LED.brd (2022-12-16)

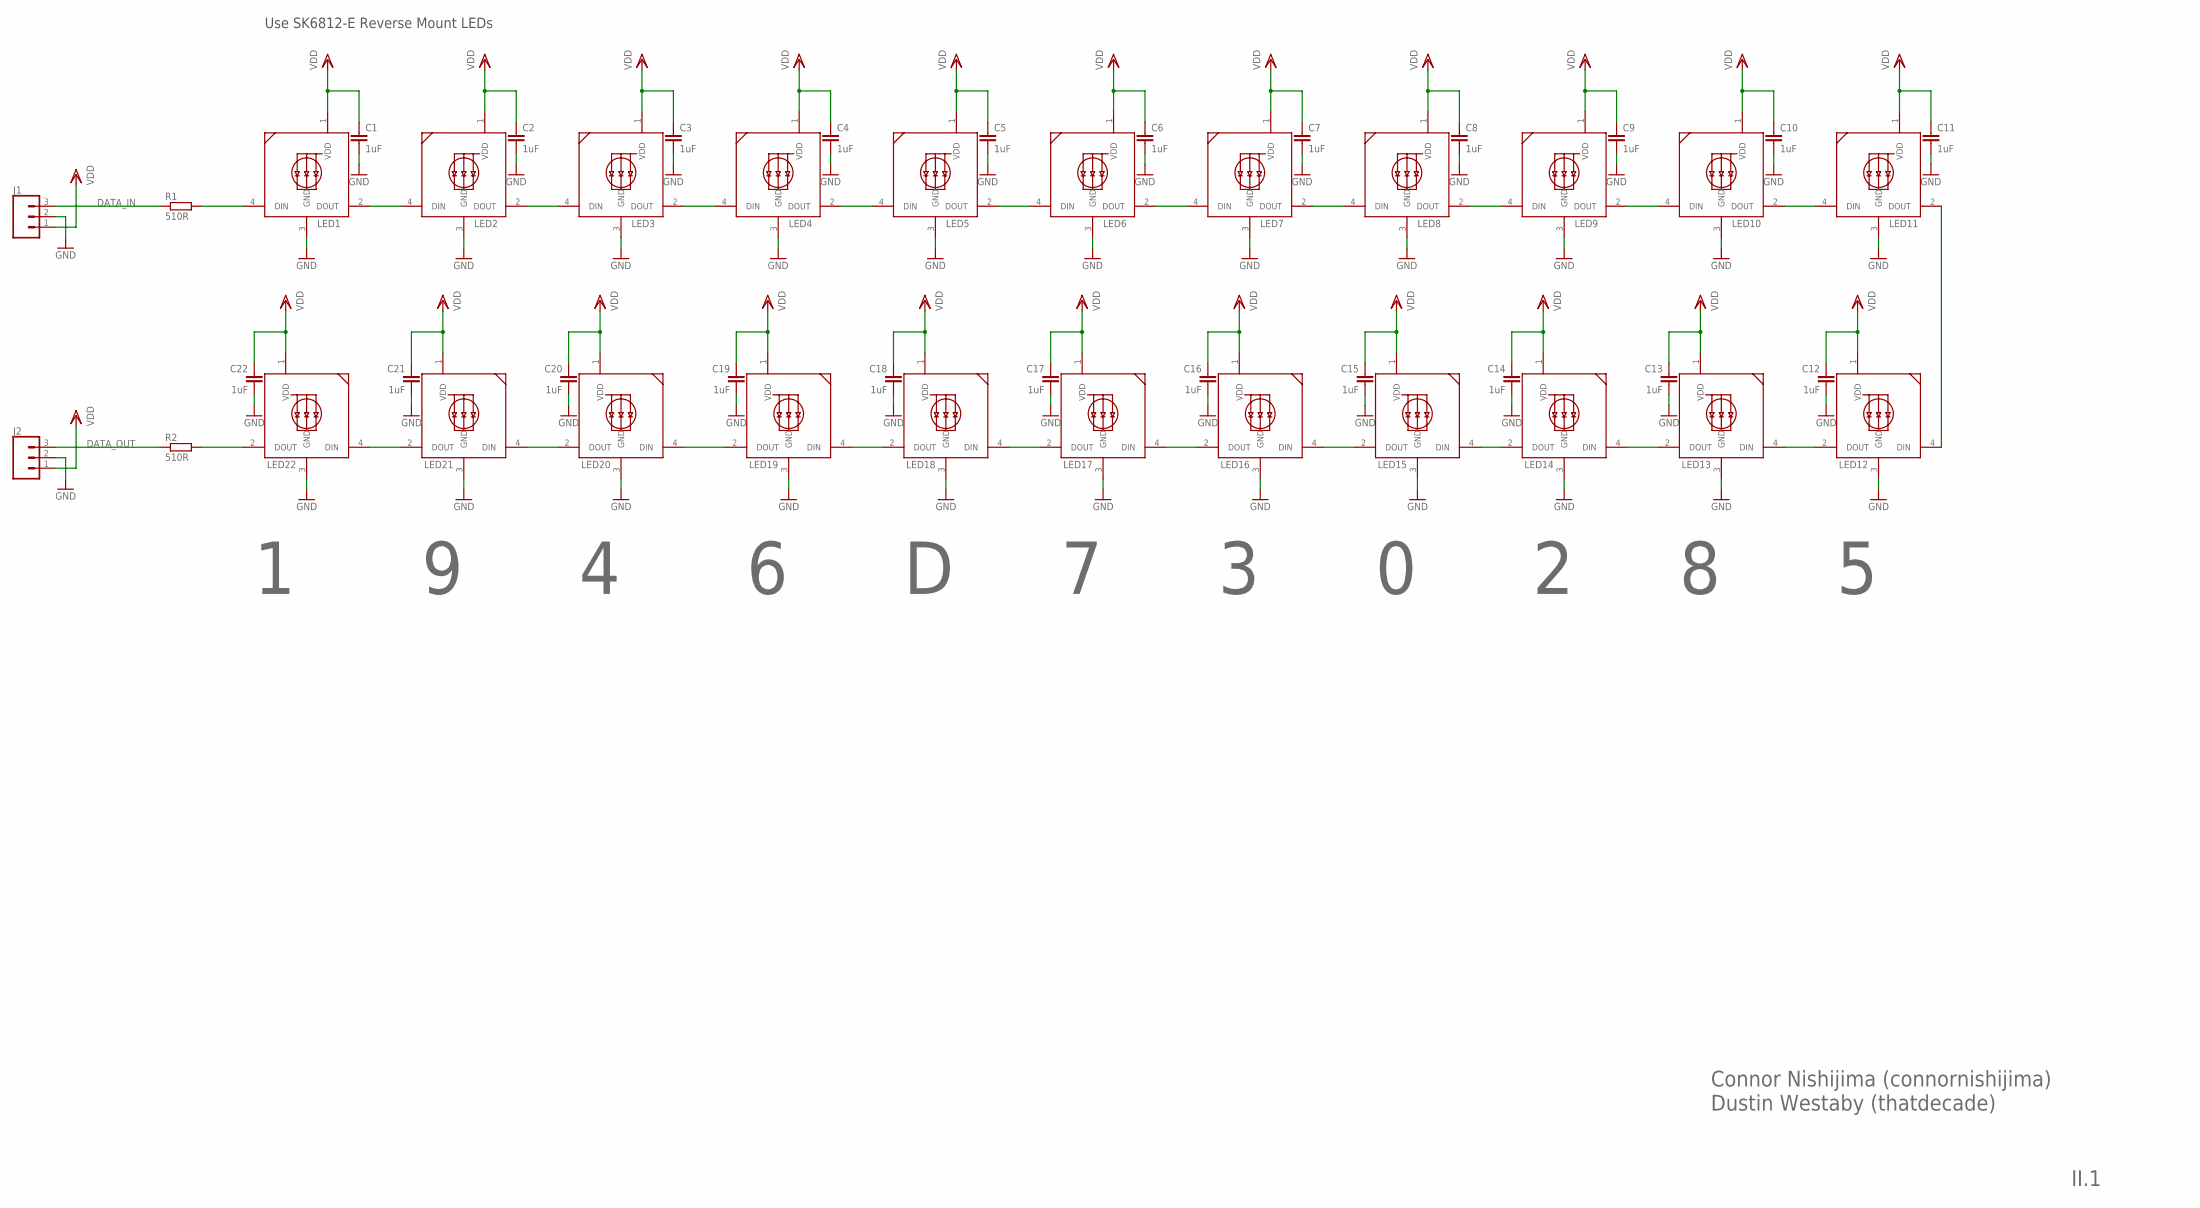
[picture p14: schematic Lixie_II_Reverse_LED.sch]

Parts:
C1, C2, C3, C4, C5, C6, C7, C8, C9, C10, C11, C12, C13, C14, C15, C16, C17, C18, C19, C20, C21, C22: 1uF; C0402
J1, J2: CONN_031X03_NO_SILK; 1X03_NO_SILK
LED1, LED2, LED3, LED4, LED5, LED6, LED7, LED8, LED9, LED10, LED11, LED12, LED13, LED14, LED15, LED16, LED17, LED18, LED19, LED20, LED21, LED22: SK6812MINI_REV; SK6812-E-SMD
R1, R2: 510R; R0402

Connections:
DATA_IN: J1.3, R1.1
DATA_OUT: J2.3, R2.1
GND: C1.2, C2.2, C3.2, C4.2, C5.2, C6.2, C7.2, C8.2, C9.2, C10.2, C11.2, C12.2, C13.2, C14.2, C15.2, C16.2, C17.2, C18.2, C19.2, C20.2, C21.2, C22.2, J1.2, J2.2, LED1.3 (GND), LED2.3 (GND), LED3.3 (GND), LED4.3 (GND), LED5.3 (GND), LED6.3 (GND), LED7.3 (GND), LED8.3 (GND), LED9.3 (GND), LED10.3 (GND), LED11.3 (GND), LED12.3 (GND), LED13.3 (GND), LED14.3 (GND), LED15.3 (GND), LED16.3 (GND), LED17.3 (GND), LED18.3 (GND), LED19.3 (GND), LED20.3 (GND), LED21.3 (GND), LED22.3 (GND)
unnamed: LED1.4 (DIN), R1.2
unnamed: LED11.2 (DOUT), LED12.4 (DIN)
unnamed: LED22.2 (DOUT), R2.2
unnamed: LED21.2 (DOUT), LED22.4 (DIN)
unnamed: LED20.2 (DOUT), LED21.4 (DIN)
unnamed: LED19.2 (DOUT), LED20.4 (DIN)
unnamed: LED18.2 (DOUT), LED19.4 (DIN)
unnamed: LED17.2 (DOUT), LED18.4 (DIN)
unnamed: LED16.2 (DOUT), LED17.4 (DIN)
unnamed: LED15.2 (DOUT), LED16.4 (DIN)
unnamed: LED14.2 (DOUT), LED15.4 (DIN)
unnamed: LED13.2 (DOUT), LED14.4 (DIN)
unnamed: LED12.2 (DOUT), LED13.4 (DIN)
unnamed: LED10.2 (DOUT), LED11.4 (DIN)
unnamed: LED9.2 (DOUT), LED10.4 (DIN)
unnamed: LED8.2 (DOUT), LED9.4 (DIN)
unnamed: LED7.2 (DOUT), LED8.4 (DIN)
unnamed: LED6.2 (DOUT), LED7.4 (DIN)
unnamed: LED5.2 (DOUT), LED6.4 (DIN)
unnamed: LED4.2 (DOUT), LED5.4 (DIN)
unnamed: LED3.2 (DOUT), LED4.4 (DIN)
unnamed: LED2.2 (DOUT), LED3.4 (DIN)
unnamed: LED1.2 (DOUT), LED2.4 (DIN)
VDD: C1.1, C2.1, C3.1, C4.1, C5.1, C6.1, C7.1, C8.1, C9.1, C10.1, C11.1, C12.1, C13.1, C14.1, C15.1, C16.1, C17.1, C18.1, C19.1, C20.1, C21.1, C22.1, J1.1, J2.1, LED1.1 (VDD), LED2.1 (VDD), LED3.1 (VDD), LED4.1 (VDD), LED5.1 (VDD), LED6.1 (VDD), LED7.1 (VDD), LED8.1 (VDD), LED9.1 (VDD), LED10.1 (VDD), LED11.1 (VDD), LED12.1 (VDD), LED13.1 (VDD), LED14.1 (VDD), LED15.1 (VDD), LED16.1 (VDD), LED17.1 (VDD), LED18.1 (VDD), LED19.1 (VDD), LED20.1 (VDD), LED21.1 (VDD), LED22.1 (VDD)

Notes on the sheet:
Dustin Westaby (thatdecade)
Connor Nishijima (connornishijima)
II.1
Use SK6812-E Reverse Mount LEDs

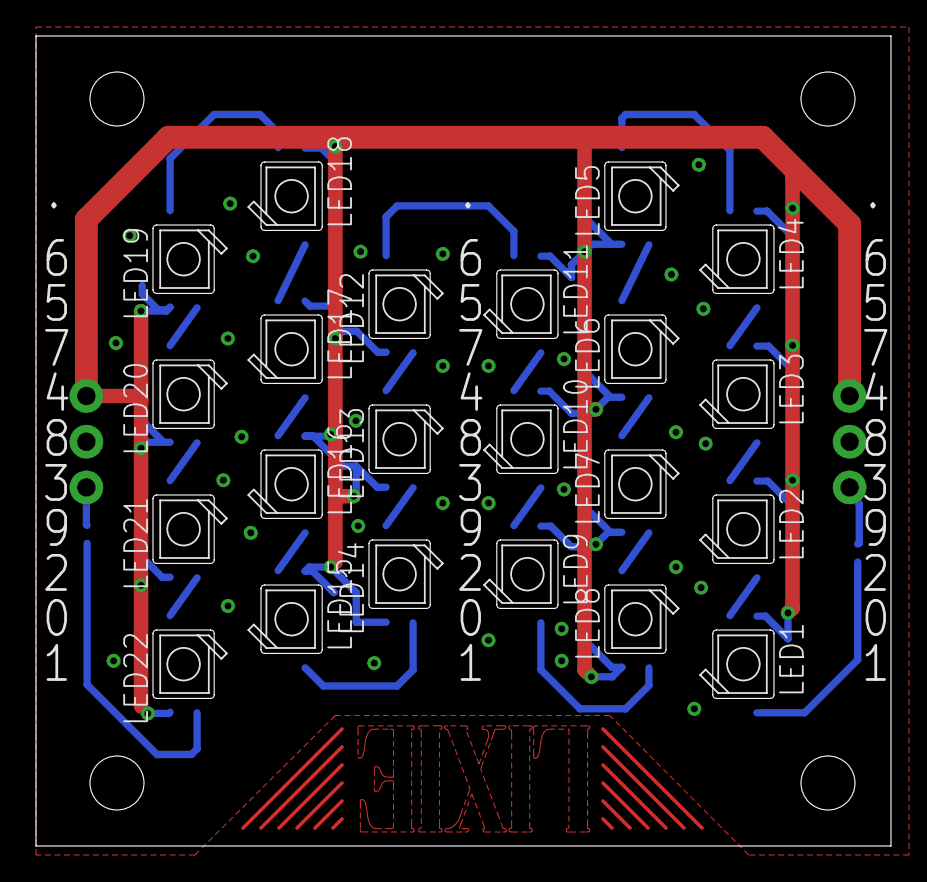
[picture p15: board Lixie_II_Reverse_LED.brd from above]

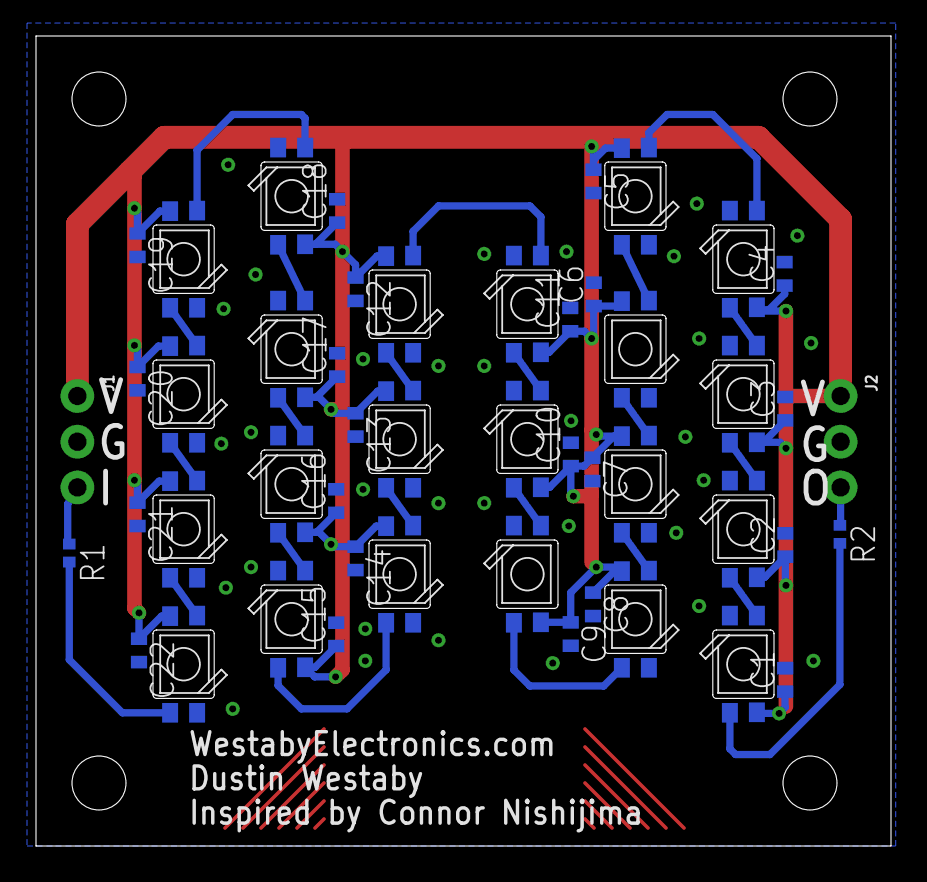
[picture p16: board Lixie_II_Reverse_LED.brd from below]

Board: 2 copper layers, 47.5 x 45.0 mm, 48 parts (26 on the bottom side), 27 nets.

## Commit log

2022-12-05 updated customizer for better splits and glue tabs
    also fixes issue #4 with parameterized window size.
    [Lixie_II_Case_2_digits.stl, Lixie_II_Case_4_digits.stl, Lixie_II_Case_6_digits.stl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]
2022-12-13 Adjusted light filter and base alignments
    Fixes issues #1 #2 #3
    [Lixie_II_Reverse_LED.brd]
2022-12-13 Adjust window sizes and wire connector placement
    Narrow the windows to prevent light leaks, open on the sides to prevent short circuits
    [LIGHTFILTER.dxf]
2022-12-13 Moved slots slightly to align with PCB
    Fixes issue #2
    [BASE2.dxf]
2022-12-15 Base part with threaded inserts
    3D printable base part with M3 heat set inserts.
    [BASE_Threaded_Inserts.stl]
2022-12-15 3D printable BASE
    [BASE-Loose_Fit.stl, BASE.scad, BASE.stl]
2022-12-15 Moves slots to align with PCB
    [BASEx2.dxf]
2022-12-15 Rotated digits 5-9 to fixes issue #5
    Rotated digits 5-9 to fix orientation of chamfered edge
    [NUM0-9.dxf]
2022-12-16 Updated bom and adjusted connector position
    [Lixie_II_Reverse_LED.brd, Lixie_II_Reverse_LED.sch, Lixie_II_Reverse_LED_BOM.xlsx]
2022-12-20 removed rogue cut path
    [NUM0-9.dxf]

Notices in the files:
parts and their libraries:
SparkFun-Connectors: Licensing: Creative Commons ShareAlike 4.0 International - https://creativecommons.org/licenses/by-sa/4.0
